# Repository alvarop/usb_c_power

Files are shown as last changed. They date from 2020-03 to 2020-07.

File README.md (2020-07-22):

# USB-C-Power

Want to replace your non USB-C power/charge cables for USB-C ones? This project lets you do just that!

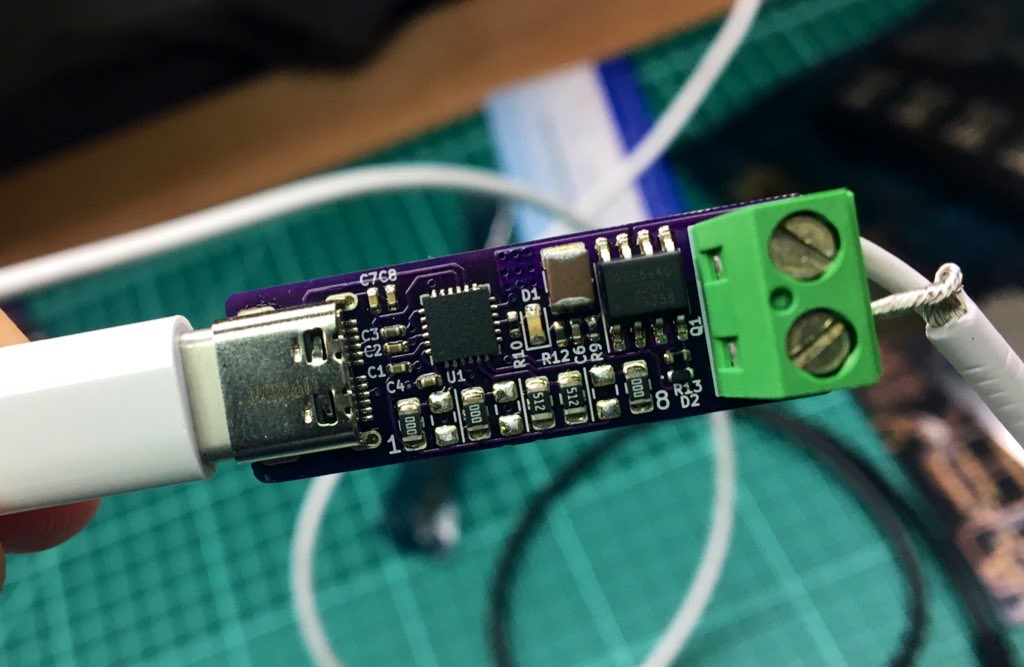
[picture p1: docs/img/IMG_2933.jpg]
USB-C-Power board


The board uses a [Cypress CYPD3177](https://www.cypress.com/file/460416/download) which will communicate with the USB power supply over USB-PD and negotiate the desired voltage and current. The voltage and current requested is set using 8 resistors that can be easily hand soldered to customize each one.

The available voltage ranges are: 5V, 9V, 12V, 15V, 19V, and 20V. You can set a minimum and maximum voltages in order to get the highest available or select just a single one so that you always know what you're getting.

The available currents range from : 0A to 5A in 0.25A increments.

If the selected voltage or current is not available, a red LED lights up and the output is disabled.

Trying to figure out which resistors to put where? Don't worry! I put together a nice calculator to do it for you. [Check it out here!](https://alvarop.com/usb_c_power/)

This board is designed to handle 5A @ 20V, but has only been tested to 3A @ 20V, so proceed with caution if you need the full 100W.

Want to build your own? Go to the [releases](https://github.com/alvarop/usb_c_power/releases) to get the files for latest stable version.

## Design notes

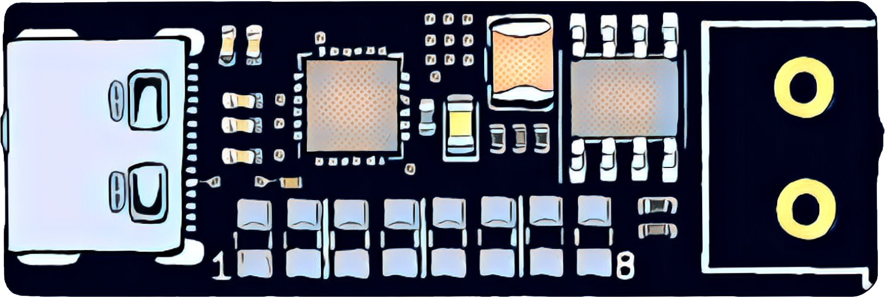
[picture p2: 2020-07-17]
docs/img/board_base.png

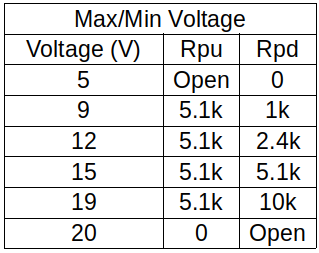
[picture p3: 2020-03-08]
tables/vmin_max_table.png

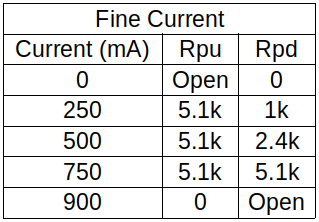
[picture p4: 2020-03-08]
tables/ifine_table.png

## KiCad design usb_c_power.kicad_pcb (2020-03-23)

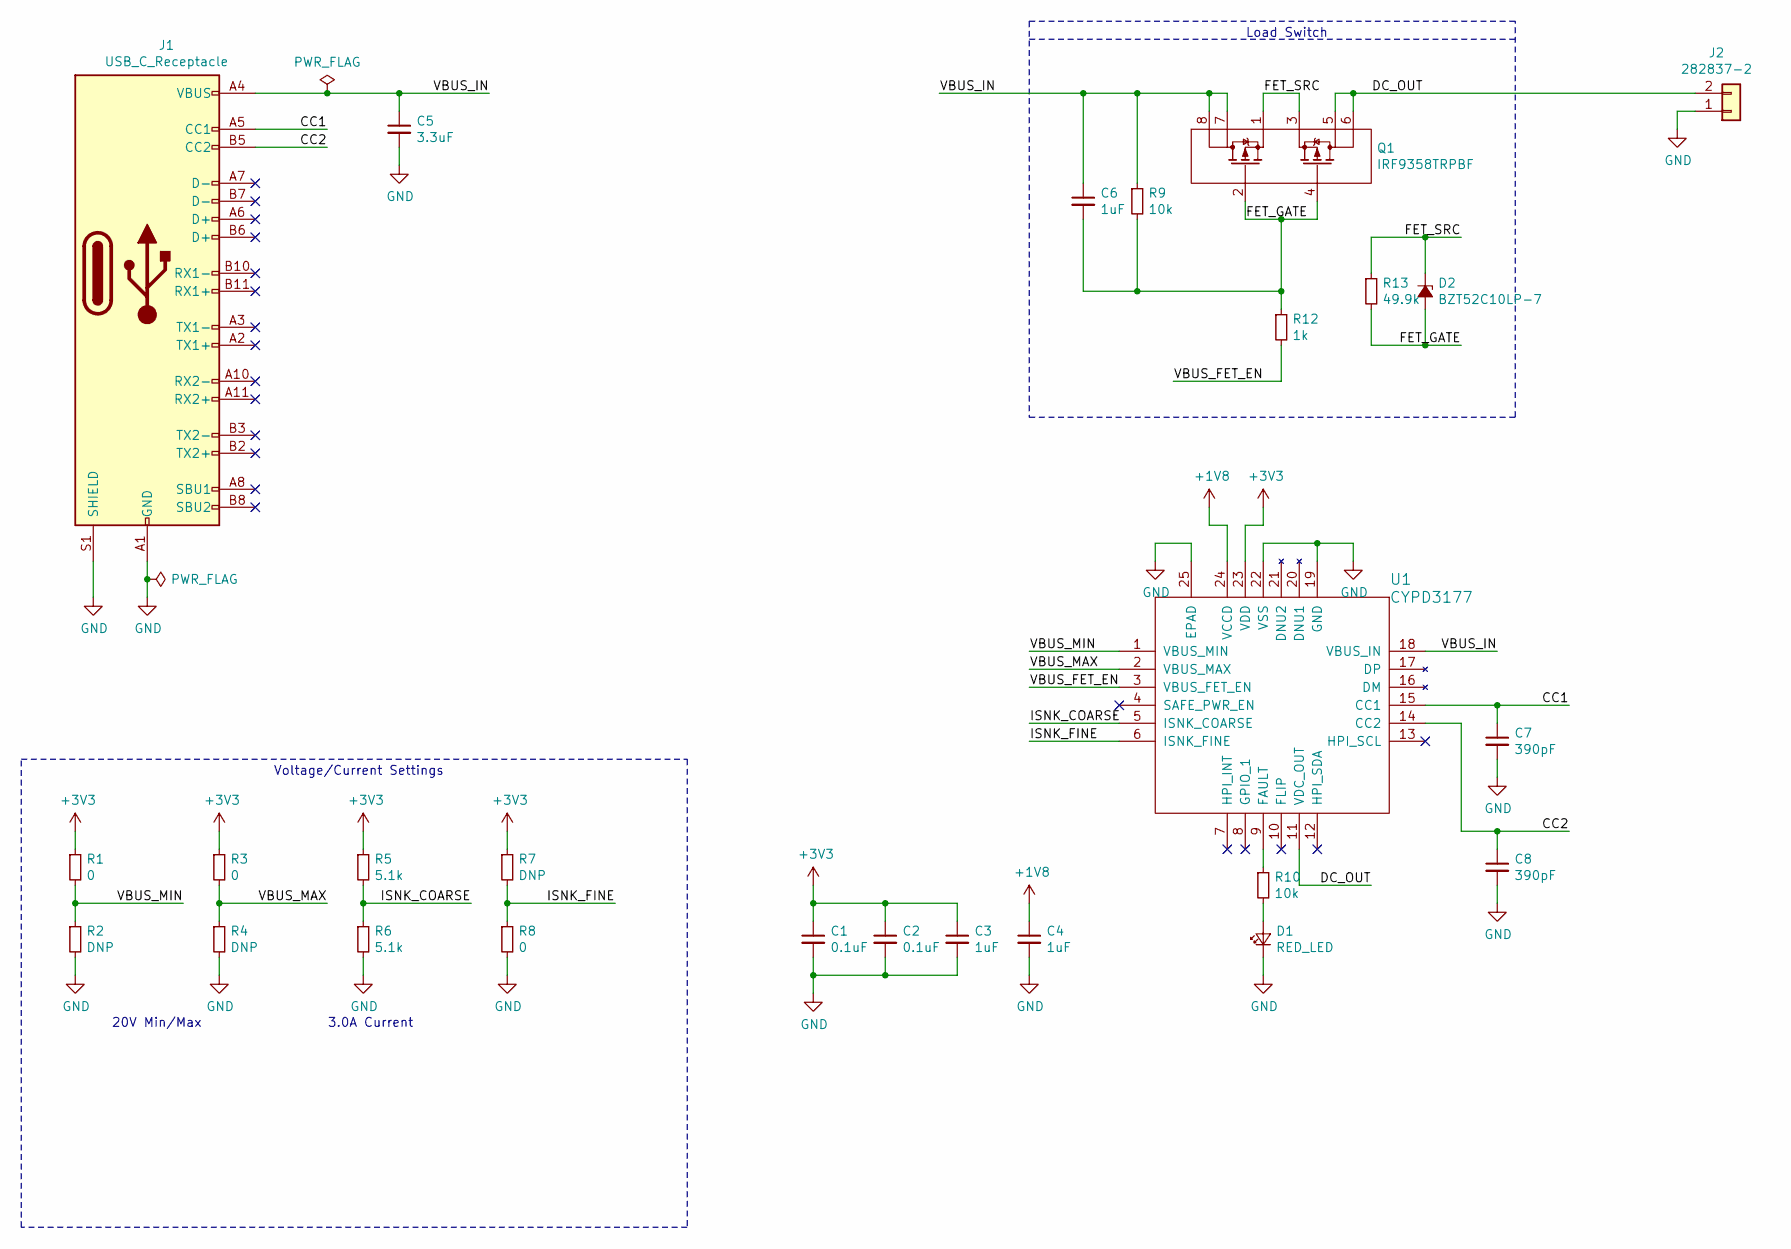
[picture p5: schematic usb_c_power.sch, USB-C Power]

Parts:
C1, C2: 0.1uF; C_0402_1005Metric; Voltage - Rated 10V; MPN GRM155R61A104KA01D
C3, C4: 1uF; C_0402_1005Metric; Voltage - Rated 16V; MPN CL05A105KO5NNNC
C5: 3.3uF; C_1210_3225Metric; Voltage - Rated 50V; MPN CGA6P3X7R1H335K250AB
C6: 1uF; C_0402_1005Metric; Voltage - Rated 35V; MPN C1005X5R1V105K050BE
C7, C8: 390pF; C_0402_1005Metric; MPN CL05B391KB5NNNC
D1: RED_LED; LED_0603_1608Metric; MPN SML-D12U1WT86
D2: BZT52C10LP-7; D_0402_1005Metric; MPN BZT52C10LP-7
J1: USB_C_Receptacle; MOLEX-1054500101; MPN 1054500101
J2: ‎282837-2‎; MPN 282837-2
Q1: IRF9358TRPBF; SO-8_3.9x4.9mm_P1.27mm; MPN IRF9358TRPBF
R1, R3, R8: 0; R_0805_2012Metric_Pad1.15x1.40mm_HandSolder; MPN RMCF0805ZT0R00
R2, R4, R7: DNP; R_0805_2012Metric_Pad1.15x1.40mm_HandSolder
R5, R6: 5.1k; R_0805_2012Metric_Pad1.15x1.40mm_HandSolder; MPN RMCF0805JT5K10
R9, R10: 10k; R_0402_1005Metric; MPN RC0402JR-0710KL
R12: 1k; R_0402_1005Metric; MPN CRG0402J1K0
R13: 49.9k; R_0402_1005Metric; MPN RC0402FR-0749K9L
U1: CYPD3177; QFN-24-1EP_4x4mm_P0.5mm_EP2.8x2.8mm; MPN CYPD3177-24LQXQ

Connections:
+1V8: C4.1, U1.24 (VCCD)
+3V3: C1.1, C2.1, C3.1, R1.1, R3.1, R5.1, R7.1, U1.23 (VDD)
/CC1: C7.1, J1.A5 (CC1), U1.15 (CC1)
/CC2: C8.1, J1.B5 (CC2), U1.14 (CC2)
/DC_OUT: J2.2, Q1.5, Q1.6, U1.11 (VDC_OUT)
/FET_GATE: C6.2, D2.2 (A), Q1.2, Q1.4, R9.2, R12.1, R13.2
/FET_SRC: D2.1 (K), Q1.1, Q1.3, R13.1
/ISNK_COARSE: R5.2, R6.1, U1.5 (ISNK_COARSE)
/ISNK_FINE: R7.2, R8.1, U1.6 (ISNK_FINE)
/VBUS_FET_EN: R12.2, U1.3 (VBUS_FET_EN)
/VBUS_IN: C5.1, C6.1, J1.A4 (VBUS), J1.A9 (VBUS), J1.B4 (VBUS), J1.B9 (VBUS), Q1.7, Q1.8, R9.1, U1.18 (VBUS_IN)
/VBUS_MAX: R3.2, R4.1, U1.2 (VBUS_MAX)
/VBUS_MIN: R1.2, R2.1, U1.1 (VBUS_MIN)
GND: C1.2, C2.2, C3.2, C4.2, C5.2, C7.2, C8.2, D1.1 (K), J1.A1 (GND), J1.A12 (GND), J1.B1 (GND), J1.B12 (GND), J1.S1 (SHIELD), J2.1, R2.2, R4.2, R6.2, R8.2, U1.19 (GND), U1.22 (VSS), U1.25 (EPAD)
unnamed: D1.2 (A), R10.2
unnamed: R10.1, U1.9 (FAULT)

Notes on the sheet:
20V Min/Max
3.0A Current
Voltage/Current Settings
Load Switch

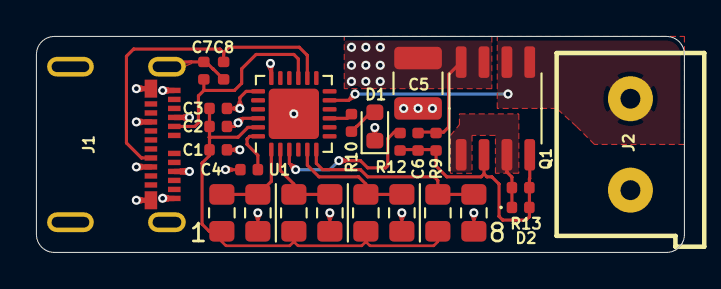
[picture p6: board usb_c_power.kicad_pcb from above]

Board: 2 copper layers, 36.0 x 12.0 mm, 26 parts (0 on the bottom side), 16 nets.

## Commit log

2020-03-08 Initial commit. First draft of schematic
    [resistor_tables.ods, usb_c_power.kicad_pcb, usb_c_power.sch]
2020-03-08 Schematic tentatively finished.
    Footprints assigned and component details added
    [usb_c_power.sch]
2020-03-09 Finished board and ordered from oshpark/oshstencil
    [usb_c_power.kicad_pcb]
2020-03-21 Created v1.1 * much larger (0805) setting resistors * 5A rated USB-C connector * Smaller 10V zener * Paste-in-hole for usb-c
    [usb_c_power.kicad_pcb, usb_c_power.sch]
2020-03-23 Finished v1.1 and ordered from oshpark
    [usb_c_power.kicad_pcb, usb_c_power.sch]
